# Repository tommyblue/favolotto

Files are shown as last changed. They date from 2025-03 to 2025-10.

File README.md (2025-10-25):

# Favolotto

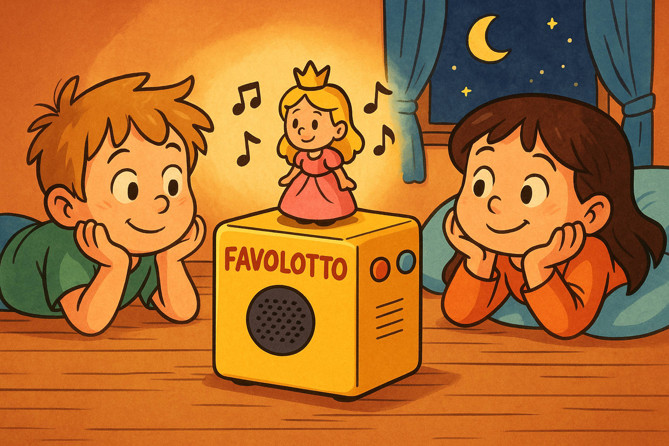
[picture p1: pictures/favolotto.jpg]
Favolotto


Favolotto is a magical audio storyteller designed to spark children’s imagination.
Just place a story character on Favolotto, and the corresponding tale begins to play—automatically and effortlessly.  
With a simple and intuitive web interface, parents can easily upload new MP3 stories and link them to specific characters using NFC tags.  
While Favolotto is made with kids in mind, it's built on the versatile Raspberry Pi Zero platform, making it a powerful and flexible audio player that can bring any NFC-tagged audio content to life.

Favolotto is ready to use, but there's still plenty of work ahead. Here’s a list of features we’d like to develop next:

- Set the Raspberry Pi OS to read-only mode, except during file uploads.
- Enhance the UI to display additional details for each MP3 file, such as duration.
- Enable MP3 downloads directly from the UI.
- If the device is paused and a different tag is placed, the new file should start playing automatically.
- Stop playback a few seconds after a tag is removed, and resume from the same point if the same tag is placed again.
- Support multiple MP3 files per tag and allow track skipping via a button.
- Monitor battery level and play a warning sound when it's low.
- Play a short sound to indicate the system is ready after startup.
- Implement automatic shutdown or hibernation after a period of inactivity.
- Create an installer to setup the device

> on 10-25-2025 I gave a talk about Favolotto at Linux Day in Prato. You can find the slides (in italian) at [linux-day-2025-slides-it.pdf](./linux-day-2025-slides-it.pdf)

## Hardware

- [Raspberry Pi Zero 2 W](https://www.raspberrypi.com/products/raspberry-pi-zero-2-w/) or [Raspberry Pi Zero W](https://www.raspberrypi.com/products/raspberry-pi-zero-w/)
- [Keyestudio 5V ReSpeaker 2-Mic Pi HAT V1.0](https://www.keyestudio.com/products/keyestudio-5v-respeaker-2-mic-pi-hat-v10-expansion-board-for-raspberry-pi-3b-4b)
- PN532 or PN7150 NFC reader
- 3 Watt speaker
- MicroSD card
- Battery hat (optional)
- Adehesive NFC tags (Ntag 215)
- 3D printed case

Assembling favolotto is quite straightforward: the hat modules (audio and the optional battery hat) use the standard Rpi shield connections. The NFC module can be connected with 4 wires using the standard I2C connection. See the NFC paragraph below for details.

## Software

Use [Raspberry Pi Imager](https://www.raspberrypi.com/software/) to prepare the MicroSD card with the Raspberry Pi OS Lite 64bit, using custom setup to configure wireless settings. Also, enable SSH.
Boot the Rpi with the SD card inserted and connect to it through SSH.
Run `sudo raspi-config`and enable I2C (`Interface Options > I2C`). Don't forget to expand the filesystem from `Advanced Options > Expand Filesystem`.

### I2C and SPI

Before starting, enable I2C and SPI running `sudo raspi-config` and going to `Interface Options > I2C > Enable` and `Interface Options > SPI > Enable`, then reboot.  

You should then see the I2C modules loaded with `lsmod | grep i2c` and the SPI modules with `lsmod | grep spi`.

If not, try loading the modules manually:

```sh
sudo modprobe i2c-dev
sudo modprobe i2c-bcm2835
sudo modprobe spidev
sudo modprobe spi_bcm2835
```

### Audio hat

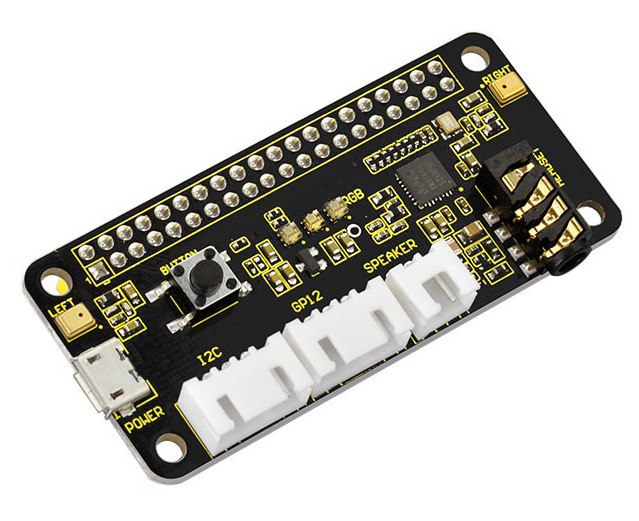
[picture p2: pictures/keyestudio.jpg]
Keyestudio 5V ReSpeaker Pi HAT


Install the I2C package and check the sound hat is correctly detected (the detected value in the matrix could be different):

```sh
sudo apt install -y i2c-tools git

sudo i2cdetect -y 1

     0  1  2  3  4  5  6  7  8  9  a  b  c  d  e  f
00:                         -- -- -- -- -- -- -- --
10: -- -- -- -- -- -- -- -- -- -- 1a -- -- -- -- --
20: -- -- -- -- -- -- -- -- -- -- -- -- -- -- -- --
30: -- -- -- -- -- -- -- -- -- -- -- -- -- -- -- --
40: -- -- -- -- -- -- -- -- -- -- -- -- -- -- -- --
50: -- -- -- -- -- -- -- -- -- -- -- -- -- -- -- --
60: -- -- -- -- -- -- -- -- -- -- -- -- -- -- -- --
70: -- -- -- -- -- -- -- --
```

Install the hat drivers:

```sh
git clone https://github.com/waveshare/WM8960-Audio-HAT
cd WM8960-Audio-HAT/
sudo ./install.sh
```

> At the moment of writing (24th sept 2025) the main branch doesn't work with the 6.12 kernel.
> You can either try with the [6.12.x](https://github.com/waveshareteam/WM8960-Audio-HAT/tree/6.12.x) branch or [this fork](https://github.com/ubopod/WM8960-Audio-HAT)

Edit the configuration with `sudo vi /boot/firmware/config.txt` and add:

```
dtparam=audio=off # this is already present with "on", change it
dtoverlay=wm8960-soundcard
```

After `reboot`, you shoud see the sound card:

```sh
$ aplay -l

**** List of PLAYBACK Hardware Devices ****
card 0: wm8960soundcard [wm8960-soundcard], device 0: 3f203000.i2s-wm8960-hifi wm8960-hifi-0 [3f203000.i2s-wm8960-hifi wm8960-hifi-0]
  Subdevices: 1/1
  Subdevice #0: subdevice #0
card 1: vc4hdmi [vc4-hdmi], device 0: MAI PCM i2s-hifi-0 [MAI PCM i2s-hifi-0]
  Subdevices: 1/1
  Subdevice #0: subdevice #0
```

Copy an mp3 file to the Rpi and check it works with `mpg321 file.mp3` (`sudo apt install mpg321` if it is not available). If you don't hear anything, check the volume with `alsamixer` (use `m` to mute/unmute channels).

To adjust the volume use `alsamixer`:

```sh
$ sudo alsamixer
# Setup the volume, in particular increase the Speaker volume at least at 80%
$ sudo alsactl store
```

To make this change permanent, you must create a boot script. First, store the settings to the settings file:

```sh
sudo alsactl -f /etc/wm8960-soundcard/wm8960_asound.state store
```

Then create the systemd file at `/etc/systemd/system/restore-wm8960-volume.service` and paste the following text:

```
[Unit]
Description=Ripristina volume WM8960
After=sound.target

[Service]
Type=oneshot
ExecStart=/usr/sbin/alsactl -f /etc/wm8960-soundcard/wm8960_asound.state restore

[Install]
WantedBy=multi-user.target
```

Then enable it:

```sh
sudo systemctl daemon-reload
sudo systemctl enable restore-wm8960-volume.service
```

After the reboot, the volume should be at the right level. You can check it with `amixer sget Speaker`.

### NFC

#### PN532 module

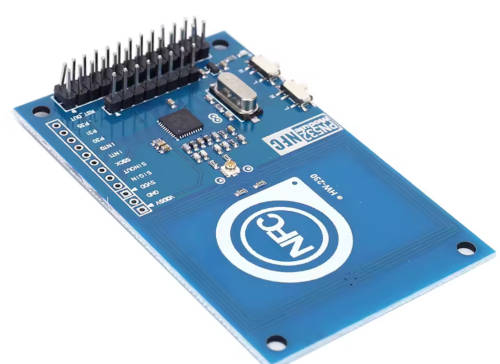
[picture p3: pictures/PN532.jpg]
PN532


Connect the module to the Rpi via I2C. The audio hat exposes the I2C port on its top. Follow the correct order:

| PN532 | Raspberry Pi Zero |
| ----- | --- |
| VCC | 3.3V (Pin 1) |
| GND | GND (Pin 6) |
| SDA | SDA1 - GPIO2 (Pin 3) |
| SCL | SCL1 - GPIO3 (Pin 5) |

> **Do not forget to set the NFC module to I2C changing the switches to 1-0.**

You should now see the device at the 0x24 or 0x48 address (0x24 in this example):

```sh
$ sudo i2cdetect -y 1

     0  1  2  3  4  5  6  7  8  9  a  b  c  d  e  f
00:                         -- -- -- -- -- -- -- --
10: -- -- -- -- -- -- -- -- -- -- UU -- -- -- -- --
20: -- -- -- -- 24 -- -- -- -- -- -- -- -- -- -- --
30: -- -- -- -- -- -- -- -- -- -- -- -- -- -- -- --
40: -- -- -- -- -- -- -- -- -- -- -- -- -- -- -- --
50: -- -- -- -- -- -- -- -- -- -- -- -- -- -- -- --
60: -- -- -- -- -- -- -- -- -- -- -- -- -- -- -- --
70: -- -- -- -- -- -- -- --
```

At this point you must configure the module editing the file `/etc/nfc/libnfc.conf`, adding/updating with:

```
allow_autoscan = true
device.connstring = "pn532_i2c:/dev/i2c-1"
# Uncomment the following line to enable verbose logging
#log_level = 3

```

Install the required packages:

```sh
sudo apt install libnfc6 libnfc-bin libnfc-dev libnfc-examples
```

Check the device:

```sh
$ nfc-list
nfc-list uses libnfc 1.8.0
NFC device:  opened
```

If everything is ok, you can try reading a tag with `nfc-poll`:

```sh
$ nfc-poll
nfc-poll uses libnfc 1.8.0
NFC reader:  opened
NFC device will poll during 36000 ms (20 pollings of 300 ms for 6 modulations)
ISO/IEC 14443A (106 kbps) target:
    ATQA (SENS_RES): 00  44
       UID (NFCID1): 04  82  28  3a  bf  2a  81
      SAK (SEL_RES): 00
Waiting for card removing...nfc_initiator_target_is_present: Target Released
done.
```

In the picture below you see another popular PN532 module, but beware that, given the position of the antenna around the other components, in my experience it doesn't work well (or doesn't work at all).

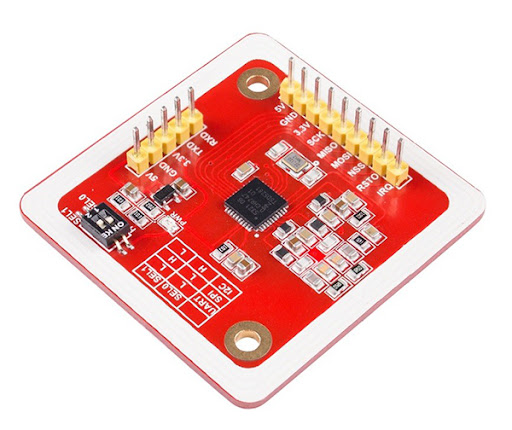
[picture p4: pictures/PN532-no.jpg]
Do not use this one


#### PN7150 module

Using the shield with the PN7150 follow the [reference guide](https://community.nxp.com/t5/NXP-Designs-Knowledge-Base/Easy-set-up-of-NFC-on-Raspberry-Pi/ta-p/1099034)

The reference code:

```
git clone https://github.com/NXPNFCLinux/linux_libnfc-nci.git
```

In this repo there are some example to use libnfc:

```
https://github.com/NXPNFCLinux/linux_libnfc-nci_examples
```

**Note**: demo and lib needs to have connected the Int pin.

#### NFC PN7150 Connection:

immagine

- Signal | Pin No.
- SDA -> GPIO 2
- SCL -> GPIO 3
- Vdd -> 3.3V
- GND -> GND
- Int -> GPIO23

#### Buttons:

- GPIO22 -> Button Left
- GPIO23 -> Button Middle
- GPIO24 -> Button Right

### Battery

I found two good options for the battery power:

#### UPS Lite V1.3 UPS Power HAT

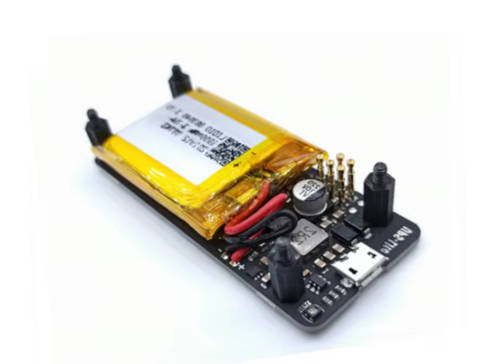
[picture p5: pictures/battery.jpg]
Battery hat


The quality is very good, but the battery doesn't last very long (I would say it will last 2 or 3 evenings). I didn't find a way to check the battery level (I tried many options, none worked).

#### 18650 module

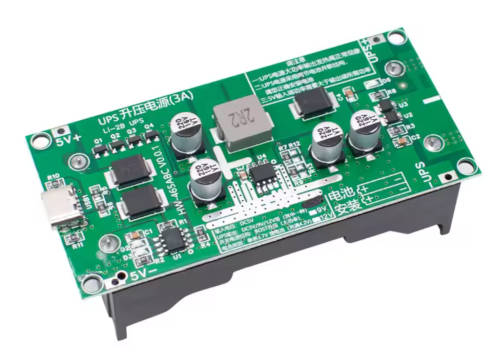
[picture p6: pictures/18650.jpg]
18650 module


Way cheaper, needs batteries (use good quality batteries). Check you're getting the 5V version while buying.

### Backend software

The heart of Favolotto is the backend, written in Go. The last version for the Raspberry can be found on the [releases page](https://github.com/tommyblue/favolotto/releases). Depending on your raspberry you must use the correct version. Run `uname -m` on the rpi and identify the version to use.

You can cross compile the software yourself. First, [install go](https://go.dev/doc/install) on your system, then build it:

```sh
cd backend
GOOS=linux GOARCH=arm64 go build -ldflags="-s -w" ./cmd/favolotto
```

Depending on the output of `uname -m` you must use the following variables:

* armv6l (Pi Zero / 1): `GOARCH=arm, GOARM=6`
* armv7l (Pi 2 / 3 / 4, 32-bit OS): `GOARCH=arm, GOARM=7`
* aarch64 (Pi Zero 2, Pi 3 / 4 / 5, 64-bit OS): `GOARCH=arm64`

Once you get the favolotto binary, copy it on your rpi into `/usr/local/bin/favolotto`.

Create the configuration file and the required folders:

```sh
mkdir /etc/favolotto
mkdir -p /var/favolotto/store
```

Create the `/etc/favolotto/config.json` file with the following content (customize it at your needs):

```json
{
    "host": "127.0.0.1",
    "port": 3000,
    "store": "/var/favolotto/store",
    "development": false,
    "nfc_driver": "pn532"
}
```

For the `nfc_driver` field use either `pn532` or `pn7150` depending on your hardware.

In the [system/](./system) folder get the `favolotto.service` file and put it into `/etc/systemd/system/favolotto.service`. Then run:

```sh
daemon-reload
systemctl enable favolotto
systemctl start favolotto
```

Now the last step: install nginx as web proxy in front of the backend and the web UI:

```sh
sudo apt install nginx
```

Then get the [system/nginx.default_server](./system/nginx.default_server) file and copy it (or its content) to `/etc/nginx/sites-enabled/default`, then restart the service with `systemctl restart nginx`.

To check if the backend is working you can open the `http://<favolotto IP>/api/v1/songs` URL to get the songs list as a JSON response. Follow the next step to also get the web UI.

### Web UI

To build the frontend you need [NodeJS](https://nodejs.org), then:

```sh
cd frontend
npm ci
npm run build
```

At this point copy the content of the `dist/` folder into `/var/www/html`. 

Once everything is in place you can open the web interface just connecting to the Favolotto ip address using a browser.

If you place an NFC tag on the reader, you'll see the tag id on the web form. Copy that value on the input and add an mp3 file. Once the upload has completed, using the NFC tag will make Favolotto reproduce the mp3 file.

### 3D models

In the 3d folder you can find some useful models:

- **token:** it's the base of the story characters. It has a hole in the middle. In your preferred slicer pause the 3D print before the hole gets closed to insert an NFC token (I used [these tokens](https://it.aliexpress.com/item/1005006302799813.html))
- **stand:** you can print multiple stands and use them to build a wall of characters. See the picture above for an example.

These are some good characters models I found online:

- [Hungry Caterpillar](https://www.printables.com/model/32061-hungry-caterpillar-with-leaf-stand-mmu)
- [Gnome 1](https://www.printables.com/model/643048-holiday-gnome) - [Gnome 2](https://www.printables.com/model/342049-gnome-supportless)
- [Snow white](https://www.printables.com/model/1197280-funko-pop-snow-white)
- [Pig](https://www.printables.com/model/1126189-cute-pig)
- [Elf](https://www.printables.com/model/1058958-xmas-elf-2)
- [Cinderella](https://www.printables.com/model/378961-cinderella-slipper)
- [Aladdin's Genie](https://www.printables.com/model/148764-aladins-genie)
- [Nemo](https://www.printables.com/model/567445-nemo)
- [Elsa](https://www.printables.com/model/639198-elsa-princess-frozen)

### Result

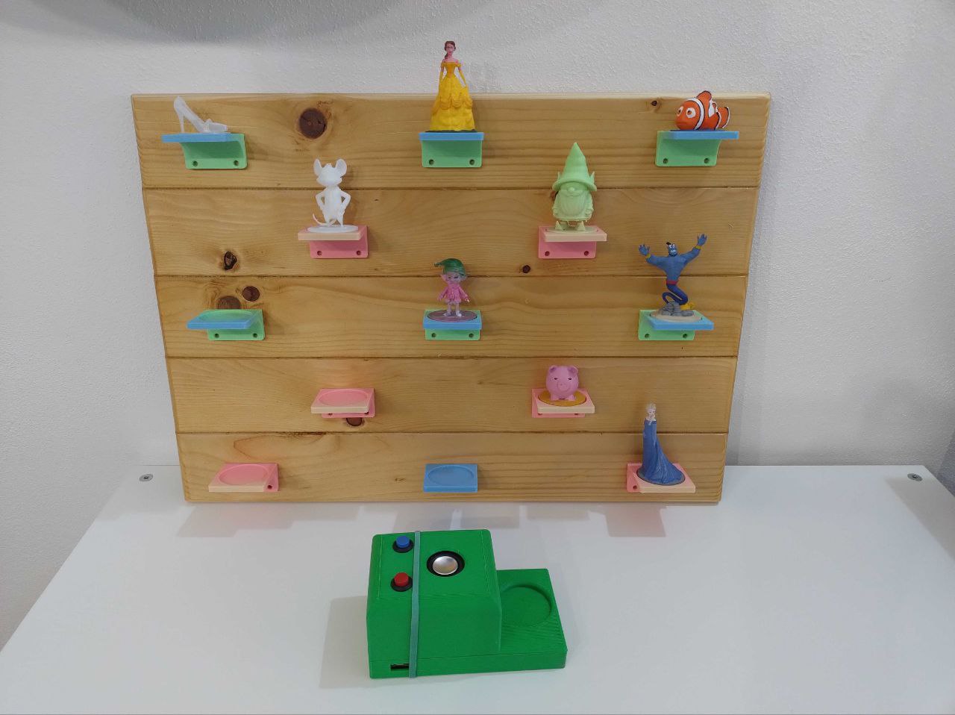
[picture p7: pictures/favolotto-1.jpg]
Favolotto wall


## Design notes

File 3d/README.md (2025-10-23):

# 3D Models

This folder contains the 3D models for Favolotto:

* **boxv3 bottom:** the bottom part of the box that holds the Raspberry Pi Zero, the audio shield, and the PN532 NFC module
* **boxv3 top:** the top part of the box, where two buttons and the speaker are installed. It snaps onto the bottom part
* **token:** includes space inside for a 25x1 mm NFC token. The print should be paused to insert the token. It can be used as the base of a character
* **stand:** useful for building a display stand for the printed characters

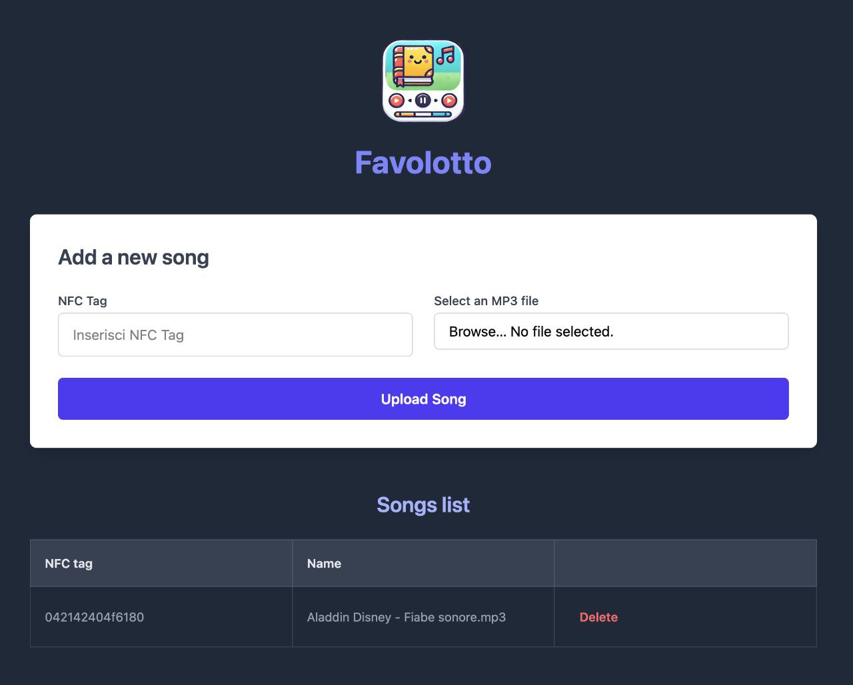
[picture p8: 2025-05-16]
pictures/web.jpg

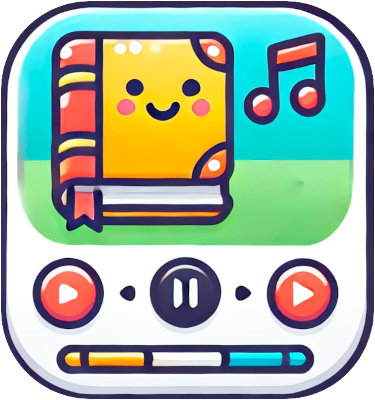
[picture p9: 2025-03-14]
frontend/public/assets/favolotto.png

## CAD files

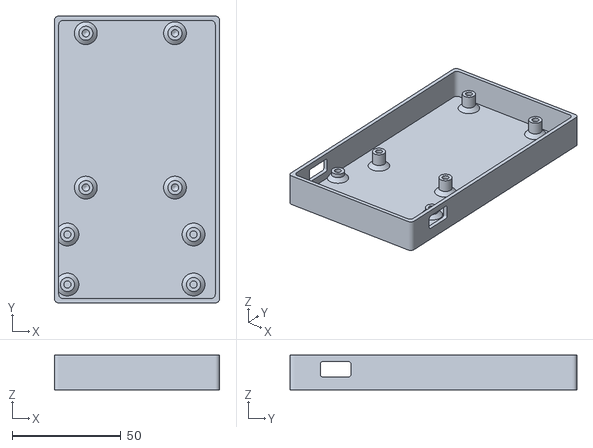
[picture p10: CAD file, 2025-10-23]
3d/boxv3 bottom v27.stl
76.0 x 132.0 x 16.0

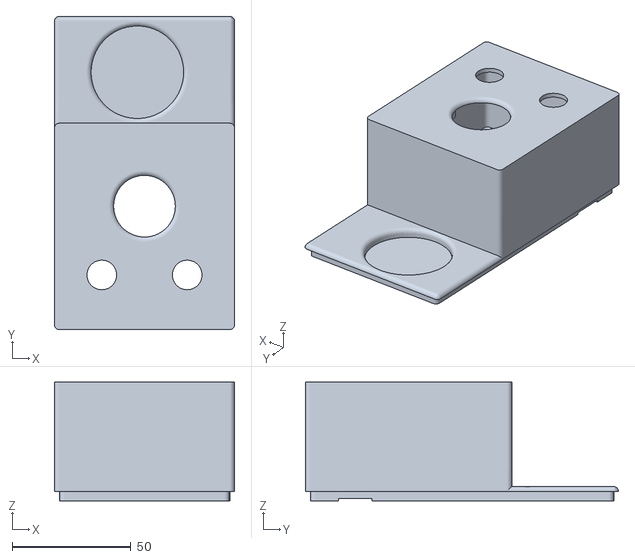
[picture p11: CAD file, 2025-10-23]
3d/boxv3 top v27.stl
76.0 x 132.0 x 50.0

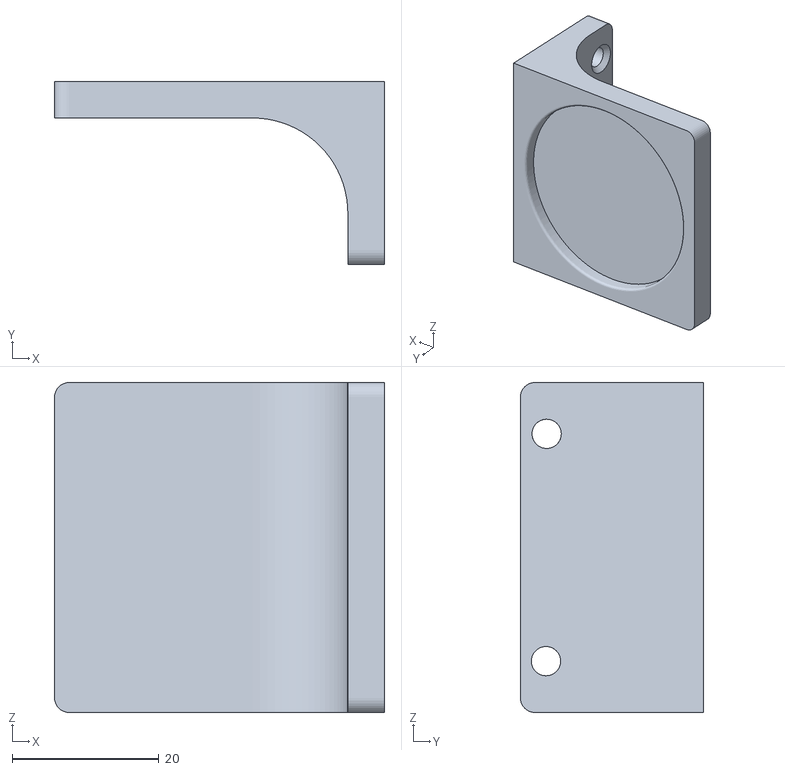
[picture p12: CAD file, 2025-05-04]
3d/stand v1.stl
45.0 x 25.0 x 45.0

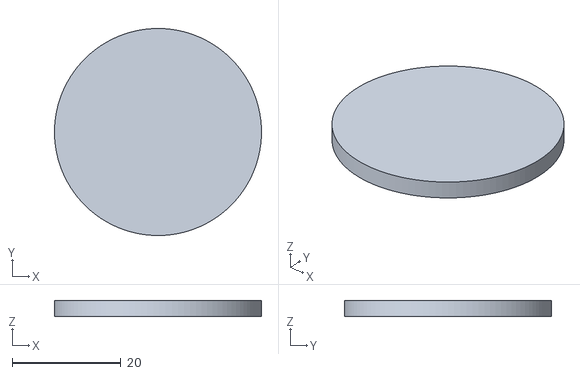
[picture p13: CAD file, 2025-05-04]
3d/token.stl
38.0 x 38.0 x 3.00

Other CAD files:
3d/boxv3 bottom v27.f3d
3d/boxv3 top v27.f3d
3d/stand v1.f3d
3d/token.f3d

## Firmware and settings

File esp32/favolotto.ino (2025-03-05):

#include <Wire.h>
#include <Adafruit_GFX.h>
#include <Adafruit_ILI9341.h>
#include <Adafruit_PN532.h>
// #include <DFRobotDFPlayerMini.h>
#include <Arduino.h>
#include <WiFi.h>
#include <ESPAsyncWebServer.h>
#include <SD.h>
#include <SPI.h>
#include "SPIFFS.h"

#include "credentials.h"

extern const char *SSID;
extern const char *PASSWORD;

// Configurazioni hardware
#define TFT_CS 5
#define TFT_RST 22
#define TFT_DC 21
#define SDA_PIN 21  // Pin SDA per I2C
#define SCL_PIN 22  // Pin SCL per I2C
// #define RX_PIN 16   // Pin RX per DFPlayer Mini
// #define TX_PIN 17   // Pin TX per DFPlayer Mini

// Definizione pin per SPI SD
#define SD_CS_PIN 5  // Chip Select per microSD
#define SD_MOSI 23
#define SD_MISO 19
#define SD_SCK 18

// Inizializza il display TFT
// Adafruit_ILI9341 tft = Adafruit_ILI9341(TFT_CS, TFT_DC, TFT_RST);

// Inizializza il lettore NFC
Adafruit_PN532 nfc(SDA_PIN, SCL_PIN);

// Inizializza il DFPlayer per la riproduzione MP3
// DFRobotDFPlayerMini myDFPlayer;

// Inizializzazione del server
// AsyncWebServer server(80);


// const char INDEX_HTML[] PROGMEM = R"=====(
// <!DOCTYPE html>
// <html lang="en">
//   <head>
//     <meta charset="UTF-8" />
//     <meta name="viewport" content="width=device-width, initial-scale=1.0" />
//     <title>Vite + React</title>
//     <script type="module" crossorigin src="/index.js"></script>
//     <link rel="stylesheet" crossorigin href="/index.css">
//   </head>
//   <body>
//     <div id="root"></div>
//   </body>
// </html>
// )=====";

// const char INDEX_JS[] PROGMEM = R"=====(
// (alert("here"))();
// )=====";

// const char INDEX_CSS[] PROGMEM = R"=====(
// body {background-color:red;}
// )=====";


void setup() {
  Serial.begin(115200);
  Serial.println("Inizializzazione del sistema...");

  // Connessione WiFi
  WiFi.begin(SSID, PASSWORD);
  while (WiFi.status() != WL_CONNECTED) {
    delay(1000);
    Serial.println("Connessione WiFi...");
  }
  Serial.println("Connesso!");
  IPAddress myIP = WiFi.localIP();
  Serial.println(myIP);

  // if (!SPIFFS.begin(true)) {
  //   Serial.println("Errore nell'inizializzazione di SPIFFS!");
  //   return;
  // }

  // Serial.println("SPIFFS montato correttamente!");

  // File fileHtml = SPIFFS.open("/index.html", "w");
  // if (!fileHtml) {
  //   Serial.println("Errore nella creazione del file");
  //   return;
  // }
  // fileHtml.println(INDEX_HTML);
  // fileHtml.close();

  // File fileJs = SPIFFS.open("/index.js", "w");
  // if (!fileJs) {
  //   Serial.println("Errore nella creazione del file");
  //   return;
  // }
  // fileJs.println(INDEX_JS);
  // fileJs.close();

  // File fileCss = SPIFFS.open("/index.css", "w");
  // if (!fileCss) {
  //   Serial.println("Errore nella creazione del file");
  //   return;
  // }
  // fileCss.println(INDEX_CSS);
  // fileCss.close();


  // Inizializzazione SD
  SPI.begin(SD_SCK, SD_MISO, SD_MOSI, SD_CS_PIN);
  if (!SD.begin(SD_CS_PIN)) {
    Serial.println("Errore nell'inizializzazione della SD!");
    // return;
  }

  Serial.println("SD pronta!");

  listSDFiles();

  // Avvia il display TFT
  // tft.begin();
  // tft.setRotation(3);
  // tft.fillScreen(ILI9341_WHITE);

  // Avvia il lettore NFC
  nfc.begin();
  uint32_t versiondata = nfc.getFirmwareVersion();
  if (!versiondata) {
    Serial.println("Impossibile trovare il lettore NFC");
  } else {
    Serial.println(versiondata);
  }

  // Avvia il DFPlayer utilizzando Serial2
  // Serial2.begin(9600, SERIAL_8N1, RX_PIN, TX_PIN);
  // if (!myDFPlayer.begin(Serial2)) {
  //   Serial.println("DFPlayer non trovato");
  // }
  // myDFPlayer.volume(20);
  // myDFPlayer.play(1);

  // int value = myDFPlayer.readFileCounts();
  // if (value == -1) {  //Error while Reading.
  //   printDetail(myDFPlayer.readType(), myDFPlayer.read());
  // } else {  //Successfully get the result.
  //   Serial.println(value);
  // }

  // if (myDFPlayer.available()) {
  //   printDetail(myDFPlayer.readType(), myDFPlayer.read());  //Print the detail message from DFPlayer to handle different errors and states.
  // }

  // Endpoint GET per ottenere la lista delle storie
  // server.on("/stories", HTTP_GET, [](AsyncWebServerRequest *request) {
  //   File root = SD.open("/");
  //   if (!root) {
  //     request->send(500, "text/plain", "Errore apertura SD");
  //     return;
  //   }

  //   String json = "[";
  //   File file = root.openNextFile();
  //   while (file) {
  //     if (!file.isDirectory() && String(file.name()).endsWith(".mp3")) {
  //       json += "{\"name\":\"" + String(file.name()) + "\"}";
  //       if (root.openNextFile()) json += ",";
  //     }
  //     file.close();
  //     file = root.openNextFile();
  //   }
  //   json += "]";
  //   request->send(200, "application/json", json);
  // });

  // // Endpoint POST per caricare una storia (MP3 e immagine)
  // server.on("/stories", HTTP_POST, [](AsyncWebServerRequest *request) {
  //   request->send(200, "text/plain", "Caricamento non ancora implementato");
  // });

  // // Servire l'app React dalla SD
  // server.on("/", HTTP_GET, [](AsyncWebServerRequest *request) {
  //   // request->send(SD, "/index.html", "text/html");
  //   request->send(SPIFFS, "/index.html", "text/html;charset=UTF-8");
  // });

  // server.on("/index.js", HTTP_GET, [](AsyncWebServerRequest *request) {
  //   request->send(SPIFFS, "/index.js", "text/javascript;charset=UTF-8");
  // });

  // server.on("/index.css", HTTP_GET, [](AsyncWebServerRequest *request) {
  //   request->send(SPIFFS, "/index.css", "text/css;charset=UTF-8");
  // });

  // server.begin();

  Serial.println("Sistema pronto!");
}

void loop() {
  uint8_t success;
  uint8_t uid[] = { 0, 0, 0, 0, 0, 0, 0 };
  uint8_t uidLength;
  success = nfc.readPassiveTargetID(PN532_MIFARE_ISO14443A, uid, &uidLength);

  if (success) {
    Serial.print("Tag NFC rilevato: ");
    for (int i = 0; i < uidLength; i++) {
      Serial.print(" 0x");
      Serial.print(uid[i], HEX);
    }
    Serial.println("");
  }
}

// void printDetail(uint8_t type, int value) {
//   switch (type) {
//     case TimeOut:
//       Serial.println(F("Time Out!"));
//       break;
//     case WrongStack:
//       Serial.println(F("Stack Wrong!"));
//       break;
//     case DFPlayerCardInserted:
//       Serial.println(F("Card Inserted!"));
//       break;
//     case DFPlayerCardRemoved:
//       Serial.println(F("Card Removed!"));
//       break;
//     case DFPlayerCardOnline:
//       Serial.println(F("Card Online!"));
//       break;
//     case DFPlayerUSBInserted:
//       Serial.println("USB Inserted!");
//       break;
//     case DFPlayerUSBRemoved:
//       Serial.println("USB Removed!");
//       break;
//     case DFPlayerPlayFinished:
//       Serial.print(F("Number:"));
//       Serial.print(value);
//       Serial.println(F(" Play Finished!"));
//       break;
//     case DFPlayerError:
//       Serial.print(F("DFPlayerError:"));
//       switch (value) {
//         case Busy:
//           Serial.println(F("Card not found"));
//           break;
//         case Sleeping:
//           Serial.println(F("Sleeping"));
//           break;
//         case SerialWrongStack:
//           Serial.println(F("Get Wrong Stack"));
//           break;
//         case CheckSumNotMatch:
//           Serial.println(F("Check Sum Not Match"));
//           break;
//         case FileIndexOut:
//           Serial.println(F("File Index Out of Bound"));
//           break;
//         case FileMismatch:
//           Serial.println(F("Cannot Find File"));
//           break;
//         case Advertise:
//           Serial.println(F("In Advertise"));
//           break;
//         default:
//           break;
//       }
//       break;
//     default:
//       break;
//   }
// }

void listSDFiles() {
  File root = SD.open("/");
  if (!root) {
    Serial.println("Errore apertura SD!");
    return;
  }

  Serial.println("File nella microSD:");
  File file = root.openNextFile();
  while (file) {
    Serial.println(file.name());
    file.close();
    file = root.openNextFile();
  }
}

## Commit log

2025-03-11 move esp32 code to dedicated folder
2025-03-17 use audio module button to pause/resume
2025-03-17 manage leds
2025-03-17 use led colors to show current audio status
2025-03-27 frontend: read current tag
2025-03-31 fix to use with current interface
2025-03-31 Refactor to have a generic interface for nfc devices
2025-03-31 manage nfc driver with config
2025-03-31 use build tags to choose nfc drivers
2025-04-10 use multiple buttons
2025-05-04 3d: add token and stand 3d models
    [stand v1.f3d, stand v1.stl, token.f3d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]
2025-10-23 Add 3D models for the enclosure
    [boxv3 bottom v27.f3d, boxv3 bottom v27.stl, boxv3 top v27.f3d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]
